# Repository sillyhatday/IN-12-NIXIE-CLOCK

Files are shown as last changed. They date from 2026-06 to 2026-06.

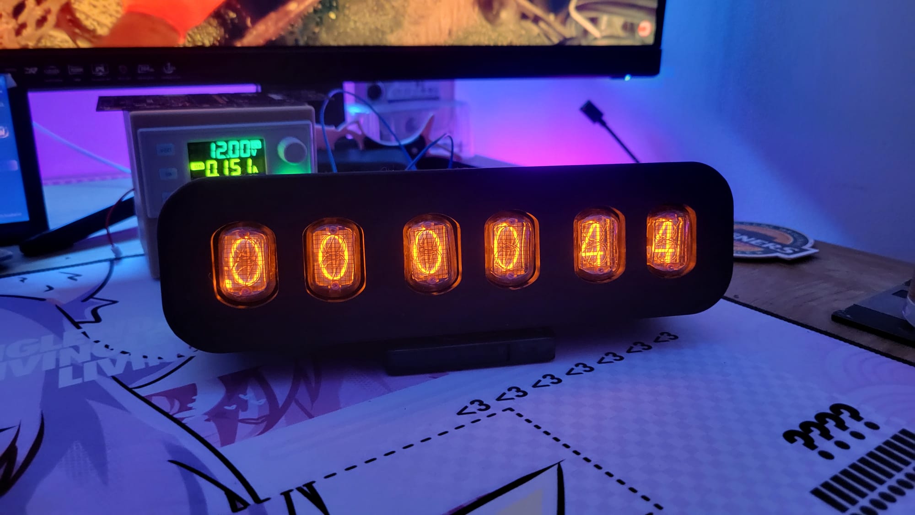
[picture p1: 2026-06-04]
PHOTOS & RENDERS/nixie clock front.jpeg

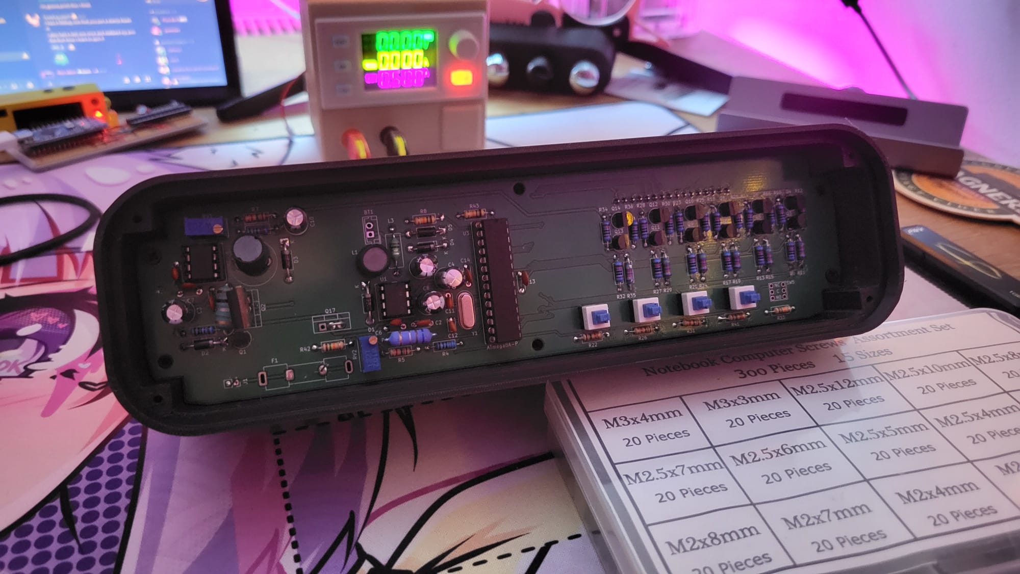
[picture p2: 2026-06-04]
PHOTOS & RENDERS/nixie clock back.jpeg

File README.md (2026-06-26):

# IN-12 Nixie Tube Clock

## Introduction

This clock was designed with the idea of using IN-12 Nixie Tubes as its display. The design was intended to look similar to something from the 1960s with a cyberpunk style. I'm not sure I have managed this or not. I think it is more art deco style.

This did not work out and I went for something that took inspo from the 1950s. I'd say more Fallout than cyberpunk. Maybe American diner or 50's American car. I like it.

The design is to be modular and 3D printing or machining friendly. The final build I would like making from aluminium or stainless steel.

---

## 🔷 Description

The internal electronics are mounted on two PCBs with a connecting pin header. One PCB for power supplies and main logic, the second for the displays and display driver. The choice of putting the display driver on the display PCB was to reduce the amount board to board connections.

The clock housing is keyed to the cut outs in the PCBs. It's not possible to put them in the wron gplace.

The logic board contains two power supplies. One power supply is for the display tube anodes. The second power supply provides power to the logic circuit.

A 9 - 12v DC supply was decided based on testing. The system will operate from 8 to 16v on the input. I have been running mine at 9v as that is supported by more USB C power supplies than 12v.

>[!NOTE]
>Before building, decide if you will use NiMH or Alkaline batteries for backup batteries. If using non-rechargable, do not populate R39 <br>
>I suggest using the ATmega328 over the ATmega8 for lower standby power and longer operation on backup batteries. <br>
>A description of operations can be found [HERE](ClockFunctions.md)

---

## 🫐 Progress

### 🟢 Done
- First revision of PCBs
- Working firmware with some features implemented.
- Stable high voltage power supply
- Case design first revision made
- All remaining case parts, buttons, legs, back cover.
- Updated PCB & fixed errors. Changed fuse, standby circuit, rearranged PCB.
- Added onboard USB-C 9 - 12v support.
- Finished adding firmware features, standby, battery backup, EEPROM clear.
- Porting to ATMEGA328 to use lower voltage and more efficient core, LOD 1.8v vs LOD 2.7v.
- Finishing case cosmetics.
- Digit ghosting fix. Problem in hardware somewhere.
- Standby code needs inverting for new 180v power control circuit.

### 🟡 Working On
- Power measurement testing. MCU power reduction on battery power.
- Tidying up lettering on the back.
- New photos of finished product and new PCBs
- LCSC or Mouser cart ready to buy.

### ⚪ Next
- Create prebuild mouser cart

---

## Photos

>[!TIP]
>Some build images can be seen [here](https://github.com/sillyhatday/IN-12-NIXIE-CLOCK/blob/main/CONCEPT%26BUILD.md)

### Complete
NixieClockFinished
nixie iv6

>[!NOTE]
>IV-6 Clock project on top. To be broken for parts for something better.

### Final PCB

NixieClockPCB

---

## Complete Parts List

| Part | Part No | Qty |
| --- | --- | --- |
| JST Connector | - | 1 |
| Capacitor | 100nF | 5 |
| Capacitor | 20pF | 2 |
| Capacitor | 1nF | 1 |
| Capacitor | 220pF | 1 |
| Capacitor | 4.7uF | 1 |
| Capacitor | 100uF | 4 |
| Diode | 1N5819 | 4 |
| Diode | UF4007 | 1 |
| Fuse | 300mA | 1 |
| Pin Header | 1x2 | 1 |
| Pin Header | 1x16 | 1 |
| Pin Socket | 1x16 | 1 |
| Inductor | 100uH | 1 |
| Inductor | 220uH | 1 |
| Inductor | 1uH | 1 |
| Transistor | BC516 1 |
| Transistor | KSP92 | 6 |
| Transistor | MPSA42 | 6 |
| Transistor | 2N3904 | 1 |
| MOSFET | IRF9540N | 1 |
| MOSFET | IRF740 | 1 |
| Resistor | 0R75 | 1 |
| Resistor | 0R1 | 1 |
| Resistor | 10K | 21 |
| Resistor | 412K | 6 |
| Resistor | 1K | 5 |
| Resistor | 15K | 1 |
| Resistor | 4K7 | 1 |
| Resistor | 100K | 1 |
| Resistor | 6K8 | 1 |
| Resistor | 1K5 | 2 |
| Resistor | 220K | 1 |
| Potentiometer | 2K | 1 |
| Potentiometer | 1K | 1 |
| Button | SHOU HAN 5.8 WSPT | 4 |
| Button | SHOU HAN 5.8 WSPT | 1 |
| MCU | ATMEGA8 | 1 |
| IC | MC34063A | 2 |
| IC | K155ID1 | 1 |
| Tube | IN-12 Nixie | 6 |
| Crystal | 1MHz | 1 |

---

## 💻 Firmware Changelog

| Version | Status | Notes |
| --- | --- | ----- |
| V1.0.0  | Initial | A generally functioning clock. 6 Digits for hours, minutes and seconds. 24 hour mode only. Flashing colon function in time with seconds changing. Reset button to clear contents of hours, minutes and seconds counters. Runs on ATmega8A and Atmega328P at 16MHz external crystal |
| V1.1.0  | Defunct | Fixed bug with hours counter not resetting properly when reset button pressed. Didn't clear hours count. Fixed bug with hours being able to go past 23 when using hours button. Incorrect modulo math |
| V1.2.0  | Defunct | 12 hour time mode added. Selectable with button. Keeps time when switching to 12 hour mode only |
| V1.3.0  | Defunct | 12 hour mode improved. No longer screwing with the hours counter. Leaving that counter alone and translating the 24 hour format on the fly. Now keeps time switching back and forth between 12/24h modes. Added display function to show what hour mode the system has been switched to. Display routine for showing the hour mode written from scratch due to brightness increase when multiplexing 2 digits vs 6 |
| V1.3.1  | Defunct | Fixed a bug caused by adding 12 hour mode functionality where in normal operation, the time doesn't wrap at 24 back to 0 |
| V1.4.0  | Defunct | Added battery backup mode to disable the MCU trying to display digits on the Nixies when 12v input is removed. Hope to save some power for running on battery power |
| V1.4.5  | Defunct | Updated the dev board to bring all features back in the code. Testing required. Moved button logic into one function. Now it is called from main |
| V1.5.0  | Defunct | Added counter for number of hours clock has been running in total. Display mode triggered when button is pressed. Hijacked the reset button for development. Run time is saved into EEPROM at addresses 0, 1, 2, 3 for unsigned long. Routine runs once. With new MCU addresses are cleared at boot and flag set in address 4 to indicate the EEPROM addresses are initialised. On boot the flag is checked, so as not to overwrite the runtime count |
V1.5.1-1.5.4 | Defunct | Various different attempts at solving the syncing issue of the colon with the seconds tick. The bug appeared after more testing. Removed ISR function that was tried in attempt to keep things in sync and in phase. Rewrote entire colon handling from scratch. Modified timer function to count 500mS ticks to use as reference for colon. Two ticks now count 1 second. Used GPIO pin to control blanking of CD4511 outputs. Removed long complex routine for multiplexing 2 digits. Reduced down to an if statement in main multiplex |
| V1.6.0  | Defunct | Added back in second multiplex routine but inside the main multiplex behind an if statement. Can't recall why I had to add it back in. Must have been buggy. At least it's more stream lined than before. Improved speed of multiplex function by tracking which digit was last displayed and only blanking that one, not all six. Huge improvement to the display crispness. Blanking just one digit saves 83% of the time it took to blank 6 digits. 5 of those did not need to be. Used digitalWriteFast library as a stop gap to using direct port manipulation much later on |
| V1.6.1  | Defunct | General tidy up of formatting. Added lots of comments and removed most comments from each line unless needed for clarity. Most comments are in the top of each function in one text block. Removed some unused variables. Removed reset button references ready to trigger reset on mode button hold, or status hold |
| V1.6.5  | Defunct | Once again removed the second multiplex function for two digit mode. No longer using any digitalWriteFast in multiplex function. Blanking digits with invalid data sent to the CD4511. This was tried before and didn't work as I didn't remember to expand the array for the new data to send. It was sending random data in RAM at that moment instead! This was needed realising that the nixie tube driver doe not have a blanking input. Nixie PSU gate control output added ready for prototype PSU and logic PCB |
| V1.7.0 | Defunct | Removed some debugging code using GPIO pins. Added an output to drive a MOSFET gate that will control the 180v boost supply, depending on 12v input being present or not. Code was added onto the section controlling display blanking as the input to perform the display blanking was already implemented |
| V1.7.1 | Defunct | Changed setup function to deal with stored EEPROM data differently and how it is initialised on first power up. Added in a basic check routine to confirm EEPROM is working, else show 999,999 on the run time display. Not sure it was needed as the problems I was having went away when shifting the EEPROM storage addresses. I think this unknown Aliexpress chip is somewhat dodgy. It is probably worn out. The chip has been reprinted on top while the underside is beat to hell |
| V1.8.0 | Defunct | Implemented a multi-function button routine. Status button now serves dual function. It is a new function in code that handles just that button, where it should be merged with the existing button handler. I don't plan on any more multi function buttons, so I'll leave this alone. Holding the status button now does a software reset of the time. Pressing the button works as before but activates on release of the button, not on the press |
| V1.8.1 | Defunct | Fixed a bug that caused the run time counter to roll over at 255 |
| V2.0.0 | Defunct | Complete rewrite of the whole software. Code is built around state machines now, no more blocking flag everywhere. Some features have been removed or not yet implemented. Missing code for standby function. Removed blinking colon, don't like it anymore |
| V2.1.0 | Defunct | Code modified to work on the real nixie tube setup. Only small things like the multiplex scan direction and stuff I've forgotten. Fixed bug with button debouncing not working great since the re-write. Attempted to fix problem with run time hours data getting messed up. Not wure why as it didnt have any issue on the dev board |
| V2.2.0 | Defunct | Added standby feature back to system. Power loss or power switch perform the same function. Displays off, 180v supply off, sleep cpu. CPU wakes once per second to keep time and check if escape standby. Not sure eeprom fix is working still. Need to add code to stop eeprom code being updated while in sleep. It's only to track tube run time |
| V2.2.3 | Current | Moved software over to ATmega328. Implemented clock divider to reduce clock speed to 2MHz. At 1MHz there was a slight percievable flicker when seconds incremented |

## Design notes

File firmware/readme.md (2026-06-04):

Firmware archive

V2.0 is a near full rewrite of the software after I learned more about programming. It's still not perfect and missing features.

V2.1 is the only version that works on the nixie tube clock build, all previous versions only work on the development board.

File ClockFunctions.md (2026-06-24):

## 🟦 Clock Functions

* The clock will power on and display time starting at 00:00:00 when it is plugged in. Whenever the clock is powered on, it will default to 24 hour mode. This only applies to the first time it is powered or the backup battery is depleted.

* The "hours" button is to increment the hours digits to the desired time, the same logic applies to the "minutes" button. The seconds count cannot be set. If the user wishes to sync the clock down to the second, the reset function can be used to set the clock back to 00:00:00. NEEDS REIMPLEMENTING IN V2.0

* To reset the clock to 00:00:00, hold down the "status" button for 3 seconds. Continuing to hold the button will keep the clock at this time until it is released, allowing it to be synchronised easily. NOT IMPLEMENTED

* The "status" button is multi-function. It is used to reset the clock time and to display the total run time of the clock with the display tubes powered on. A single press of the "status" button will show the hours counter. This information is stored in EEPROM memory and is saved permanently, unless the micro controller is reprogrammed and EEPROM is selected for erase. Powering off the clock, by removing the DC supply, and/or removing the internal backup battery, will not erase the counter.

* The counter uses an internal timer to record data. Pressing the "hours" button does not increase the recorded hours.

* When the clock is removed from USB-C power, the displays will turn off. Internally the clock is still running and keeping time, providing the backup battery is not depleted. This same condition can be entered using the "standby" button. This simulates the removal of USB-C power, but will not deplete the backup battery. The clock will continue to run in this state indefinitely.

* The clock will only record run time, when it is powered by the USB-C input. If the clock is on backup battery, the counter will no longer increment. The same applies for manually putting the clock in standby with the "standby" button.

* A 12 hour mode is selectable with the "mode" button. When the button is pressed, the display will briefly display 12 or 24, depending on the mode that has been set. The button will toggle between 12 and 24 hour modes.

* While the clock is plugged in, the backup batteries are charged at 8 - 11mA depending on the battery state of charge. When the batteries are full, they are charged constantly at 8mA. Due to the battery technology of NiMh, they can be left charging at a low current for a long time. If this function is not wanted, omit R39 and the batteries will not be charged. As the function of the batteries is to keep time during a power outage, having them charge is not critical. While plugged into USB-C power, even when in standby, they are being charged. It's likely the life of the batteries will be shortened from being on charge for so long, it may be better to remove the batteries and recharge them manually every 6 months or replace alkaline batteries once a year.

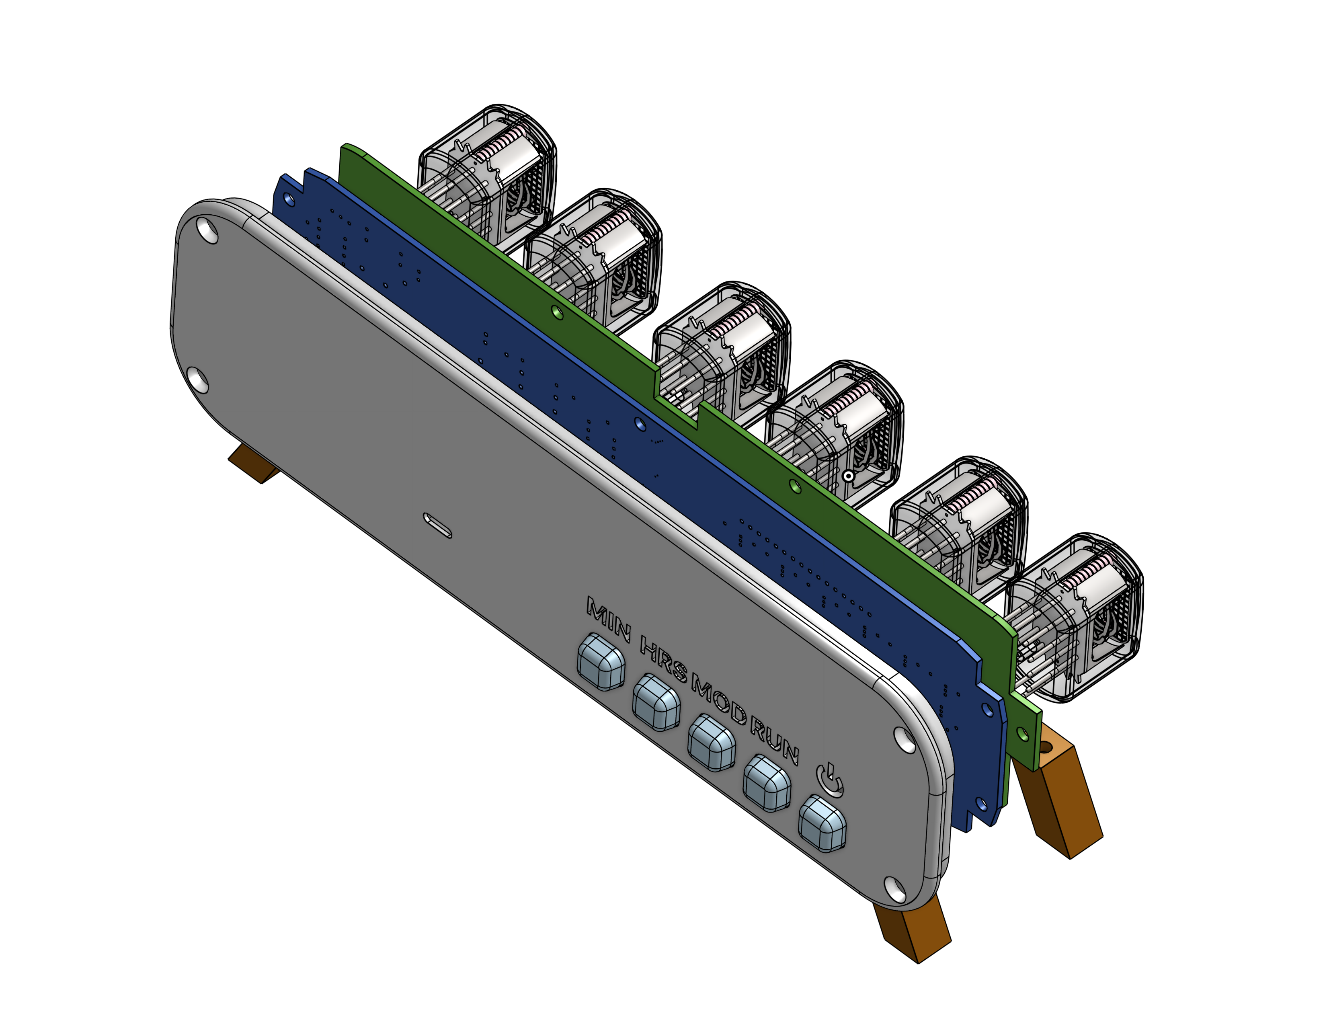
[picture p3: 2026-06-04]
PHOTOS & RENDERS/Nixie clock angled back view no body.png

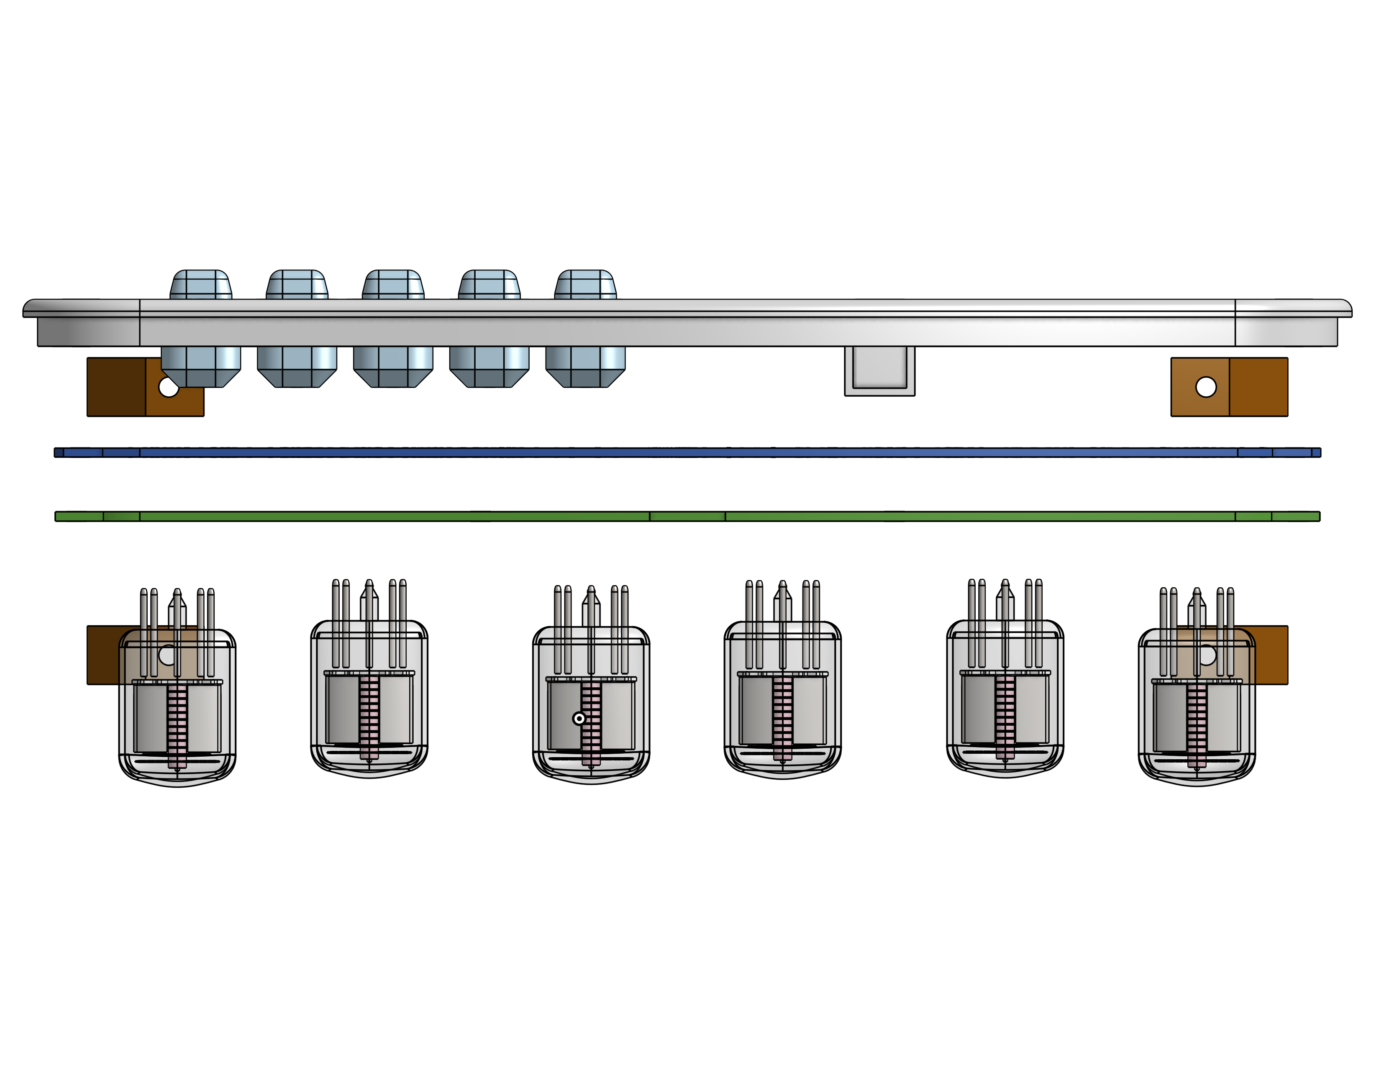
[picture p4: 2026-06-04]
PHOTOS & RENDERS/Nixie Clock Top View No Body.png

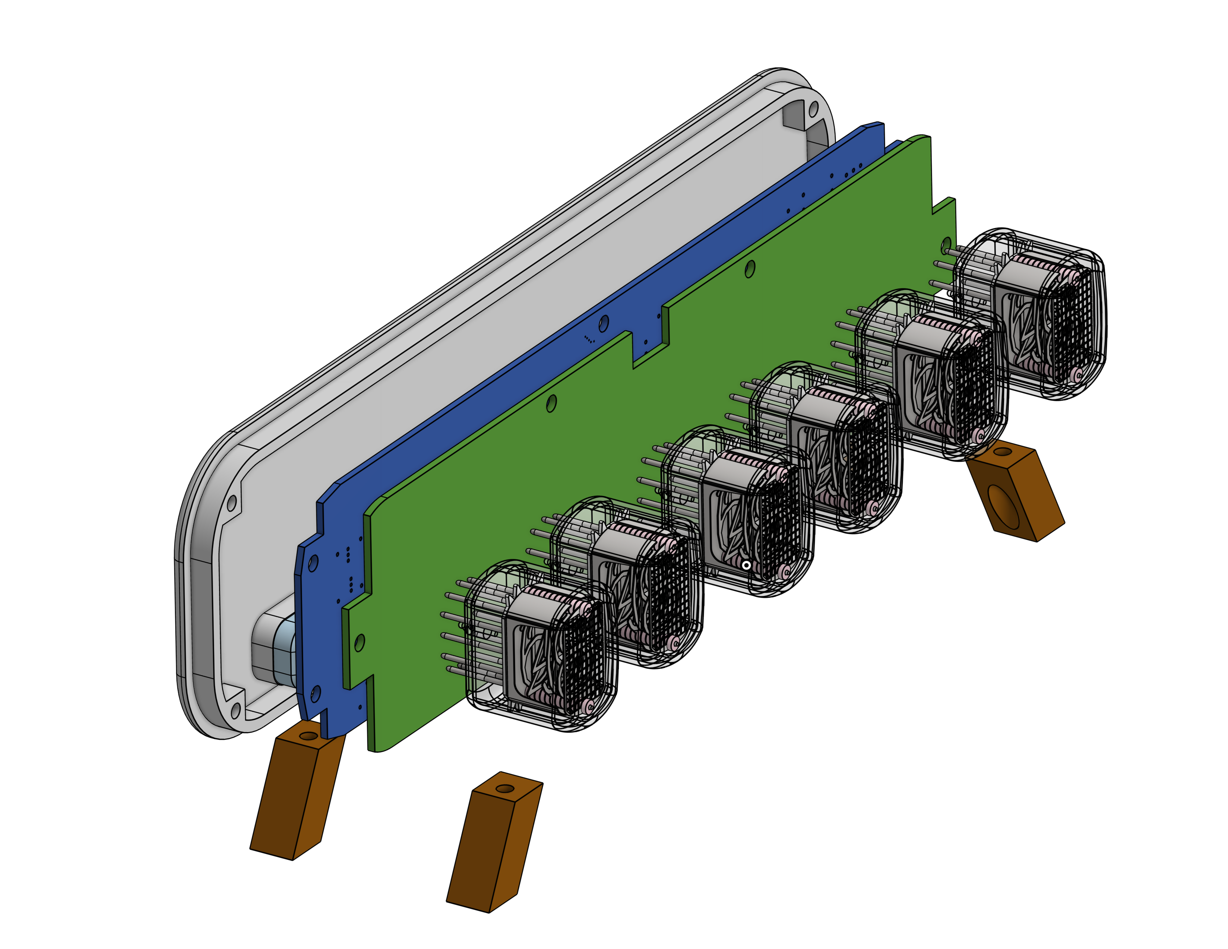
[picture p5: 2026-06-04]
PHOTOS & RENDERS/Nixie clock angled front view no body.png

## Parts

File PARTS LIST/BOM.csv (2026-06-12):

Logic PCB:
Designator | Footprint | Quantity | Value | LCSC Part # | LCSC Link | Notes
BT1, J1 | JST_EH_B2B-EH-A_1x02_P2.50mm_Vertical | 1 | Battery | C158012 | https://www.lcsc.com/product-detail/C158012.html
C1, C13, C14, C2, C7 | C_Disc_D3.4mm_W2.1mm_P2.50mm | 5 | 100nF | C2832506 | https://www.lcsc.com/product-detail/C2832506.html
C10 | CP_Radial_D6.3mm_P2.50mm | 1 | 4.7uF | C106368 | https://www.lcsc.com/product-detail/C106368.html
C11, C12 | C_Disc_D3.4mm_W2.1mm_P2.50mm | 2 | 20pF | C19712497 | https://www.lcsc.com/product-detail/C19712497.html
C3, C4, C8, C9 | CP_Radial_D6.3mm_P2.50mm | 4 | 100uF | C112509 | https://www.lcsc.com/product-detail/C112509.html
C5 | C_Disc_D3.4mm_W2.1mm_P2.50mm | 1 | 1nF | C2832504 | https://www.lcsc.com/product-detail/C2832504.html
C6 | C_Disc_D3.4mm_W2.1mm_P2.50mm | 1 | 220pF | C2169557 | https://www.lcsc.com/product-detail/C2169557.html
D1, D2, D4 | D_DO-41_SOD81_P10.16mm_Horizontal | 3 | 1N5819 | C110032 | https://www.lcsc.com/product-detail/C110032.html
D3 | D_DO-41_SOD81_P10.16mm_Horizontal | 1 | UF4007 | C511041 | https://www.lcsc.com/product-detail/C511041.html
D5 | D_DO-41_SOD81_P10.16mm_Horizontal | 1 | SB160 | C2978860 | https://www.lcsc.com/product-detail/C2978860.html
F1 | Fuseholder_Cylinder-5x20mm_Stelvio-Kontek_PTF78_Horizontal_Open | 1 | Fuse | C206887 | https://www.lcsc.com/product-detail/C206887.html
J3 | PinSocket_1x16_P2.54mm_Vertical | 1 | Logic Out | C7501270 | https://www.lcsc.com/product-detail/C7501270.html
L1 | L_Radial_D8.7mm_P5.00mm_Fastron_07HCP | 1 | 100uH | C2924234 | https://www.lcsc.com/product-detail/C2924234.html
L2 | L_Radial_D8.7mm_P5.00mm_Fastron_07HCP | 1 | 150uH | C72625 | https://www.lcsc.com/product-detail/C72625.html
L3 | L_Axial_L6.6mm_D2.7mm_P10.16mm_Horizontal_Vishay_IM-2 | 1 | 1uH | C19704338 | https://www.lcsc.com/product-detail/C19704338.html
Q1 | TO-92_Inline | 1 | BC516 | C14617 | https://www.lcsc.com/product-detail/C14617.html
Q10, Q12, Q14, Q4, Q6, Q8 | TO-92_Inline | 6 | KSP92BU | C231893 | https://www.lcsc.com/product-detail/C231893.html
Q11, Q13, Q3, Q5, Q7, Q9 | TO-92_Inline | 6 | MPSA42 | C719821 | https://www.lcsc.com/product-detail/C719821.html
Q15 | TO-220-3_Vertical | 1 | IRF9540N | C2575 | https://www.lcsc.com/product-detail/C2575.html
Q16 | TO-92_Inline | 1 | 2N3904 | C124482 | https://www.lcsc.com/product-detail/C124482.html
Q2 | TO-220-3_Vertical | 1 | IRF740 | C2570 | https://www.lcsc.com/product-detail/C2570.html
R1 | R_Axial_DIN0414_L11.9mm_D4.5mm_P15.24mm_Horizontal | 1 | 0R75 | C75144 | https://www.lcsc.com/product-detail/C75144.html
R10, R12, R13, R14, R16, R17, R18, R20, R21, R23, R25, R27, R28, R30, R32, R34, R36, R38, R42, R43, R8, R9 | R_Axial_DIN0207_L6.3mm_D2.5mm_P10.16mm_Horizontal | 22 | 10K | C2903232 | https://www.lcsc.com/product-detail/C2903232.html
R11, R15, R19, R24, R29, R35 | R_Axial_DIN0207_L6.3mm_D2.5mm_P10.16mm_Horizontal | 6 | 422K | C1367617 | https://www.lcsc.com/product-detail/C1367617.html
R2 | R_Axial_DIN0414_L11.9mm_D4.5mm_P15.24mm_Horizontal | 1 | 0R1 | C1740730 | https://www.lcsc.com/product-detail/C1740730.html
R22, R26, R3, R31, R41 | R_Axial_DIN0207_L6.3mm_D2.5mm_P10.16mm_Horizontal | 5 | 1K | C1364389 | https://www.lcsc.com/product-detail/C1364389.html
R33 | R_Axial_DIN0207_L6.3mm_D2.5mm_P10.16mm_Horizontal | 1 | 15K | C119351 | https://www.lcsc.com/product-detail/C119351.html
R37 | R_Axial_DIN0207_L6.3mm_D2.5mm_P10.16mm_Horizontal | 1 | 330R | C58577 | https://www.lcsc.com/product-detail/C58577.html
R39 | R_Axial_DIN0207_L6.3mm_D2.5mm_P10.16mm_Horizontal | 1 | 270R | C3463492 | https://www.lcsc.com/product-detail/C3463492.html | Optional
R4 | R_Axial_DIN0207_L6.3mm_D2.5mm_P10.16mm_Horizontal | 1 | 6K8 | C58600 | https://www.lcsc.com/product-detail/C58600.html
R5, R7 | R_Axial_DIN0207_L6.3mm_D2.5mm_P10.16mm_Horizontal | 2 | 1K5 | C173144 | https://www.lcsc.com/product-detail/C173144.html
R6 | R_Axial_DIN0207_L6.3mm_D2.5mm_P10.16mm_Horizontal | 1 | 220K | C172988 | https://www.lcsc.com/product-detail/C172988.html
RV1 | Potentiometer_Bourns_3296W_Vertical | 1 | 2K | C48641845 | https://www.lcsc.com/product-detail/C48641845.html
RV2 | Potentiometer_Bourns_3296W_Vertical | 1 | 1K | C48641912 | https://www.lcsc.com/product-detail/C48641912.html
SW1, SW2, SW3, SW4 | SHOU HAN 5.8 WSPT | 1 | MIN+ | C22363820 | https://www.lcsc.com/product-detail/C22363820.html
SW5 | SHOU HAN 5.8 WSPT | 1 | DISPLAY | C22363819 | https://www.lcsc.com/product-detail/C22363819.html
U1, U2 | DIP-8_W7.62mm_Socket | 2 | MC34063AP | C5180 | https://www.lcsc.com/product-detail/C5180.html
U1, U2 | DIP-8_W7.62mm_Socket | 2 | DIP 8 Socket | C2874007 | https://www.lcsc.com/product-detail/C2874007.html | Optional
U3 | DIP-28_W7.62mm_Socket | 1 | ATmega8A-P | C33901 | https://www.lcsc.com/product-detail/C33901.html
U3 | DIP-28_W7.62mm_Socket | 1 | DIP 28 Socket | C2874014 | https://www.lcsc.com/product-detail/C2874014.html | Optional
Y1 | Crystal_HC49-U_Vertical | 1 | Crystal | C5310734 | https://www.lcsc.com/product-detail/C5310734.html
Display PCB:
Designator | Footprint | Quantity | Value | LCSC Part # | LCSC Link | Notes
J1 | PinHeader_1x16_P2.54mm_Vertical | 1 | Logic In | C7499334 | https://www.lcsc.com/product-detail/C7499334.html
U1, U2, U3, U4, U5, U6 | IN-12 | 6 | IN-12A | N/A | N/A
U7 | DIP-16_W7.62mm_Socket | 1 | KN155 | N/A | N/A
U7 | DIP-16_W7.62mm_Socket | 1 | DIP 16 Socket | C72130 | https://www.lcsc.com/product-detail/C72130.html

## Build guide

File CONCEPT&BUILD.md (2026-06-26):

# Concept & Build

## Rendered Concept
Nixie clock assembled smol
Nixie clock angled rear assembled smol
Nixie clock assembled rear smol

## Internal View
nixie clock internal top view
nixie clock internal front angle
nixie clock internal back angle

## Build
nixiebuild1
nixiebuild2
nixiebuild3
nixiebuild4

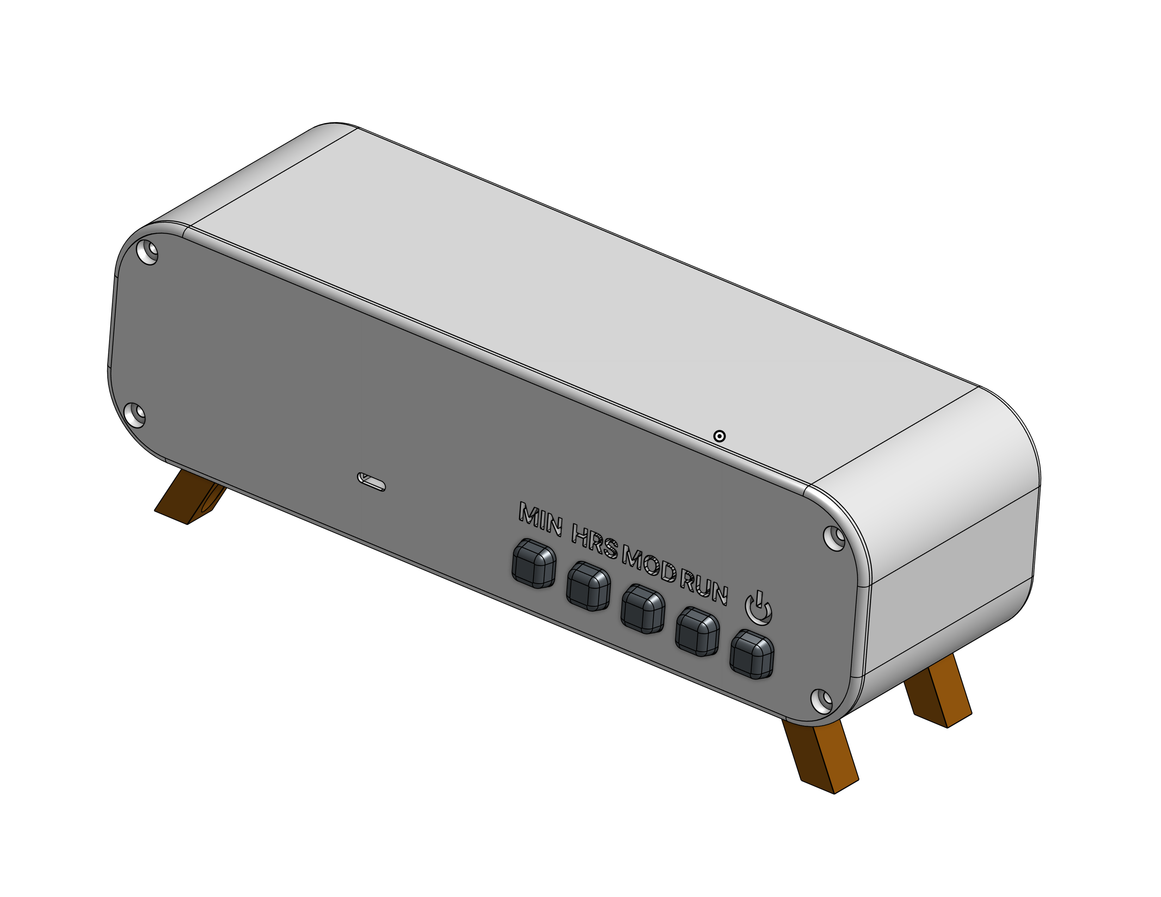
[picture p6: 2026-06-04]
PHOTOS & RENDERS/Nixie clock angled rear assembled.png

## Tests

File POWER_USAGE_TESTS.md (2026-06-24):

# Standby Power Use

>[!IMPORTANT]
>This is a work in progress

>[!NOTE]
>Standby refers to my codes standby mode, running only code needed to track time. <br>
>Sleep idle refers to the AVR hardware sleep.
>LOD watchdog uses power when enabled. This will protect the EEPROM data.

## Standby Testing

### 16MHz Clock

ATMEGA8A @16MHz:

| Standby | Sleep Idle | Analogue Comp Disabled | ADC Disabled | SPI, Timer0 & ADC Clock Disabled | LOD 1.8v Enable | Current @ 2.5v | Power Reduction |
| --- | --- | --- | --- | --- | --- | --- | --- |
| YES | NO | NO | NO | NO | N/A | ------- | --------------- |
| YES | YES | NO | NO | NO | N/A | 6.774mA | --------------- |
| YES | YES | YES | NO | NO | N/A | ------- | --------------- |
| YES | YES | YES | YES | NO | N/A | ------- | --------------- |
| YES | YES | YES | YES | YES | N/A | ------- | --------------- |
| YES | YES | YES | YES | YES | N/A | ------- | --------------- |
| YES | YES | YES | YES | NO | N/A | ------- | --------------- |

ATMEGA328P @16MHz:

| Standby | Sleep Idle | Analogue Comp Disabled | ADC Disabled | SPI, Timer0 & ADC Clock Disabled | LOD 1.8v Enable | Current @ 2.5v | Power Reduction |
| --- | --- | --- | --- | --- | --- | --- | --- |
| YES | NO | NO | NO | NO | NO | 7.288mA | 0% |
| YES | YES | NO | NO | NO | NO | 5.678mA | 28.35% |
| YES | YES | YES | NO | NO | NO | 5.639mA | 29.24% |
| YES | YES | YES | YES | NO | NO | 4.949mA | 47.26% |
| YES | YES | YES | YES | YES | NO | 5.126mA | 42.17% |
| YES | YES | YES | YES | YES | YES | ------- | ------- |
| YES | YES | YES | YES | NO | YES | 5.539mA | 31.57% |

## 4MHz Clock

ATMEGA8A @4MHz:

| Standby | Sleep Idle | Analogue Comp Disabled | ADC Disabled | SPI, Timer0 & ADC Clock Disabled | LOD 1.8v Enable | Current @ 2.5v | Power Reduction |
| --- | --- | --- | --- | --- | --- | --- | --- |
| YES | NO | NO | NO | NO | N/A | ------- | --------------- |
| YES | YES | NO | NO | NO | N/A | ------- | --------------- |
| YES | YES | YES | NO | NO | N/A | ------- | --------------- |
| YES | YES | YES | YES | NO | N/A | ------- | --------------- |
| YES | YES | YES | YES | YES | N/A | ------- | --------------- |
| YES | YES | YES | YES | YES | N/A | ------- | --------------- |
| YES | YES | YES | YES | NO | N/A | ------- | --------------- |

ATMEGA328P @4MHz:

| Standby | Sleep Idle | Analogue Comp Disabled | ADC Disabled | SPI, Timer0 & ADC Clock Disabled | LOD 1.8v Enable | Current @ 2.5v | Power Reduction |
| --- | --- | --- | --- | --- | --- | --- | --- |
| YES | NO | NO | NO | NO | NO | ------- | --------------- |
| YES | YES | NO | NO | NO | NO | ------- | --------------- |
| YES | YES | YES | NO | NO | NO | ------- | --------------- |
| YES | YES | YES | YES | NO | NO | ------- | --------------- |
| YES | YES | YES | YES | YES | NO | ------- | --------------- |
| YES | YES | YES | YES | YES | YES | ------- | --------------- |
| YES | YES | YES | YES | NO | YES | ------- | --------------- |

## 2MHz Clock

ATMEGA8A @2MHz:

| Standby | Sleep Idle | Analogue Comp Disabled | ADC Disabled | SPI, Timer0 & ADC Clock Disabled | LOD 1.8v Enable | Current @ 2.5v | Power Reduction |
| --- | --- | --- | --- | --- | --- | --- | --- |
| YES | NO | NO | NO | NO | N/A | ------- | --------------- |
| YES | YES | NO | NO | NO | N/A | ------- | --------------- |
| YES | YES | YES | NO | NO | N/A | ------- | --------------- |
| YES | YES | YES | YES | NO | N/A | ------- | --------------- |
| YES | YES | YES | YES | YES | N/A | ------- | --------------- |
| YES | YES | YES | YES | YES | N/A | ------- | --------------- |
| YES | YES | YES | YES | NO | N/A | ------- | --------------- |

ATMEGA328P @2MHz (Using CLKPR /8):

| Standby | Sleep Idle | Analogue Comp Disabled | ADC Disabled | SPI, Timer0 & ADC Clock Disabled | LOD 1.8v Enable | Current @ 2.5v | Power Reduction |
| --- | --- | --- | --- | --- | --- | --- | --- |
| YES | NO | NO | NO | NO | NO | ------- | --------------- |
| YES | YES | NO | NO | NO | NO | ------- | --------------- |
| YES | YES | YES | NO | NO | NO | ------- | --------------- |
| YES | YES | YES | YES | NO | NO | ------- | --------------- |
| YES | YES | YES | YES | YES | NO | ------- | --------------- |
| YES | YES | YES | YES | YES | YES | 4.071mA | --------------- |
| YES | YES | YES | YES | NO | YES | 4.057mA | --------------- |

## Normal Operation

### ATMEGA8A:

| Clock Speed | Input Current | Input Voltage | Input Power |
| --- | --- | --- | --- |
| @16MHz | - | - | - |
| @4MHz | - | - | - |
| @1MHz | - | - | - |

### ATMEGA328P:

| Clock Speed | Input Current | Input Voltage | Input Power |
| --- | --- | --- | --- |
| @16MHz | - | - | - |
| @4MHz | - | - | - |
| @1MHz | - | - | - |

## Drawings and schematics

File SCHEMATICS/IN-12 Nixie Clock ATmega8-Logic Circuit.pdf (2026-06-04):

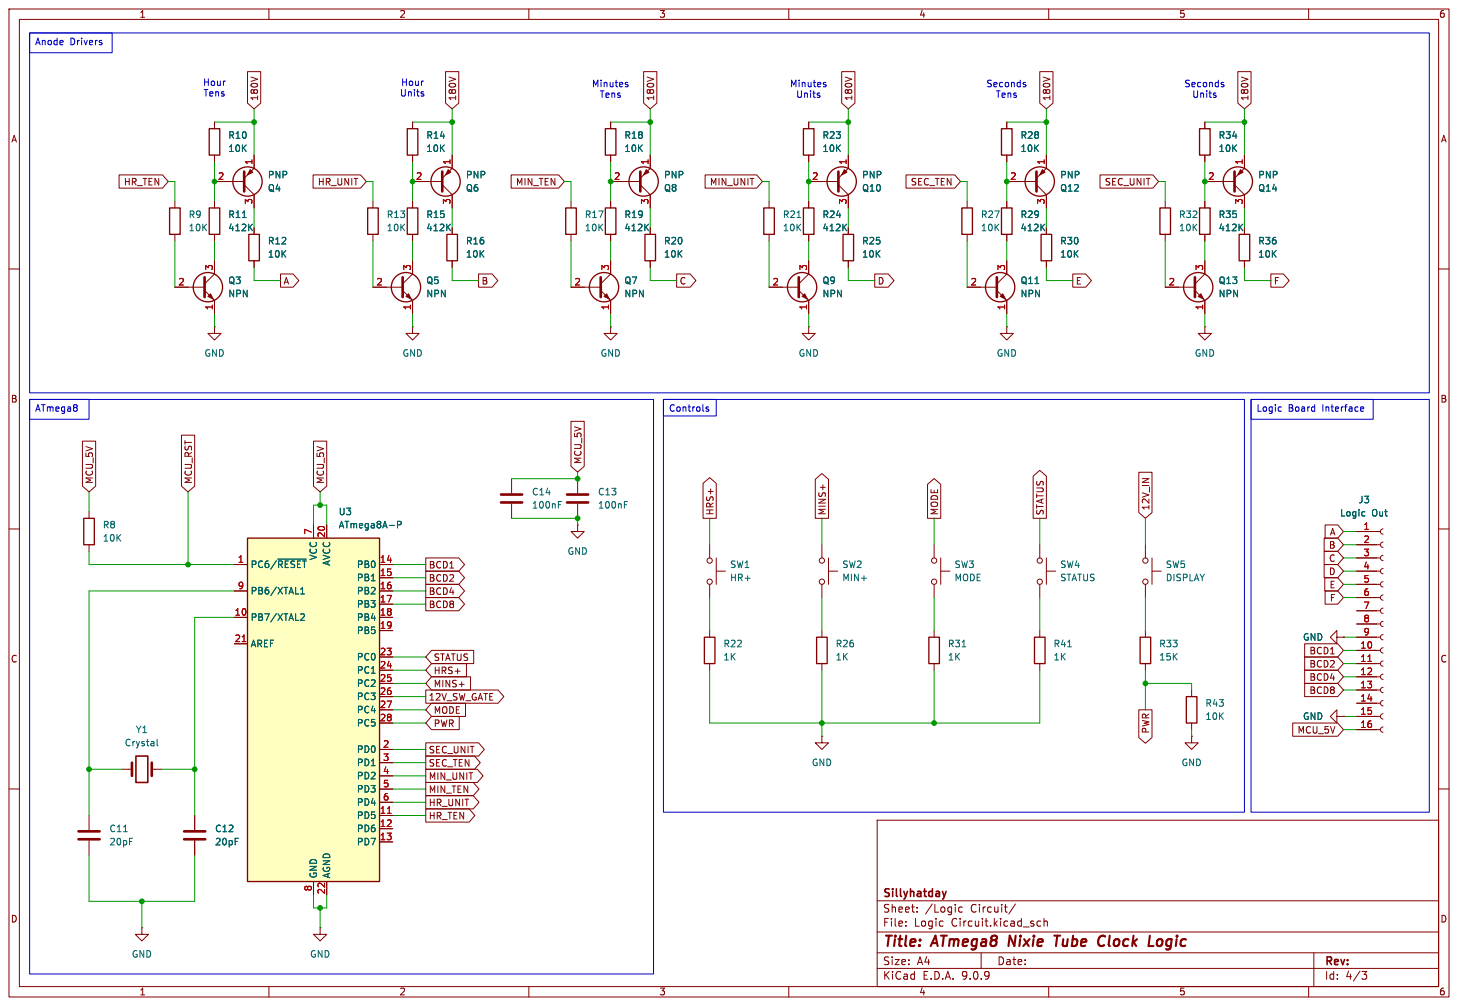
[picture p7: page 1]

3 1 Q12 PNP 180V MODE PWR STATUS

Id: 4/3 Title: ATmega8 Nixie Tube Clock Logic

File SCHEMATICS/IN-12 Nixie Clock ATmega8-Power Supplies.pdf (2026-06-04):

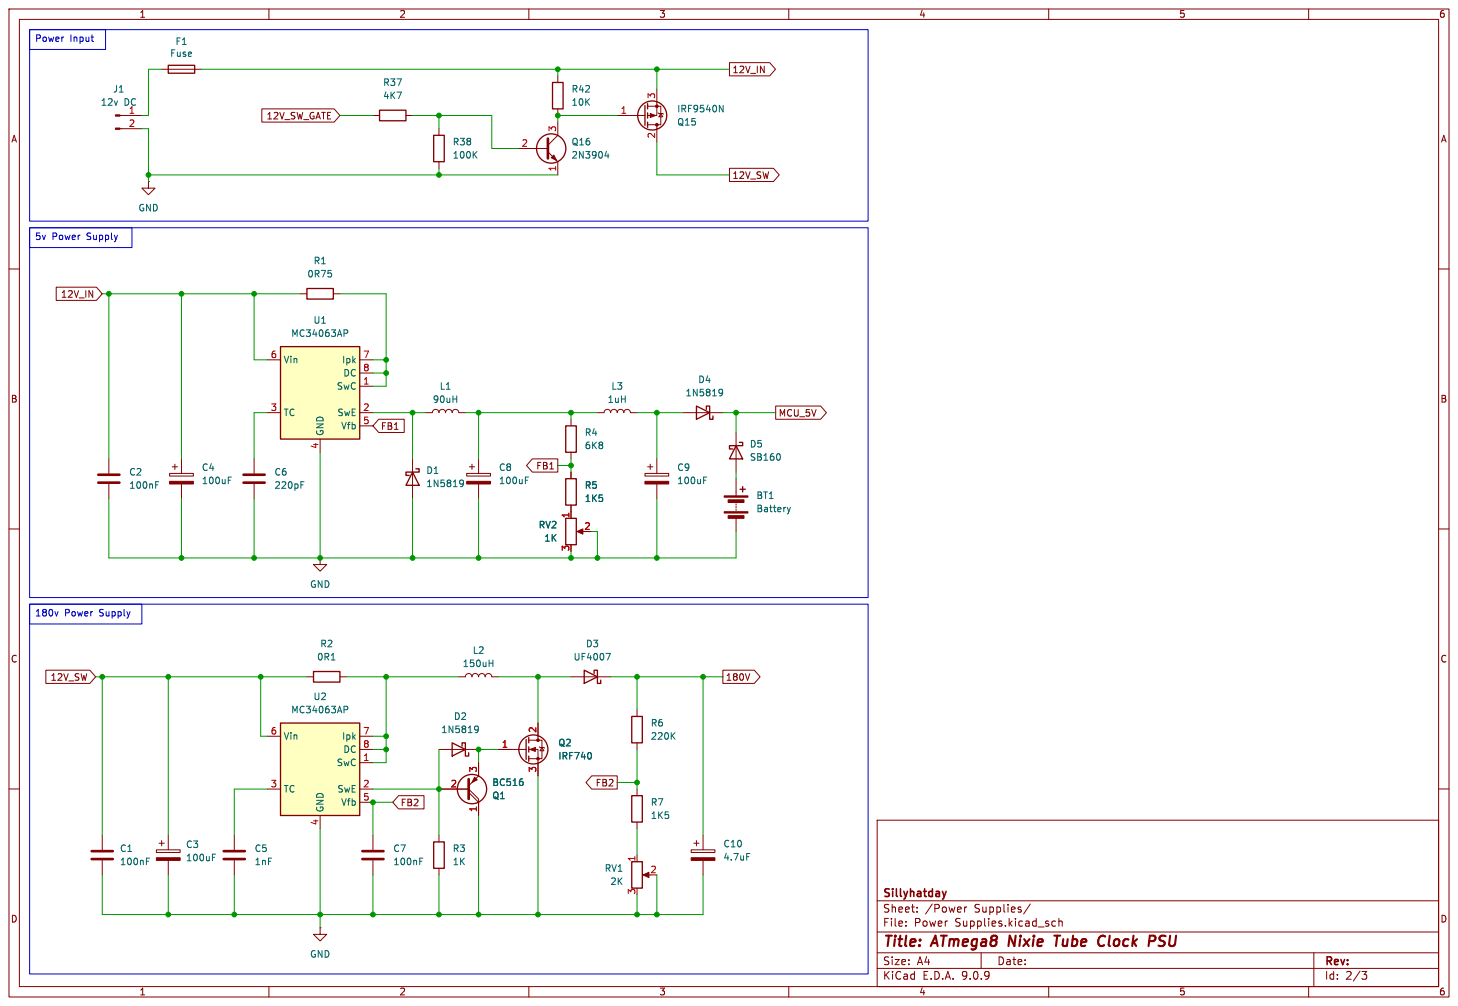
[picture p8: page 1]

Id: 2/3 Title: ATmega8 Nixie Tube Clock PSU

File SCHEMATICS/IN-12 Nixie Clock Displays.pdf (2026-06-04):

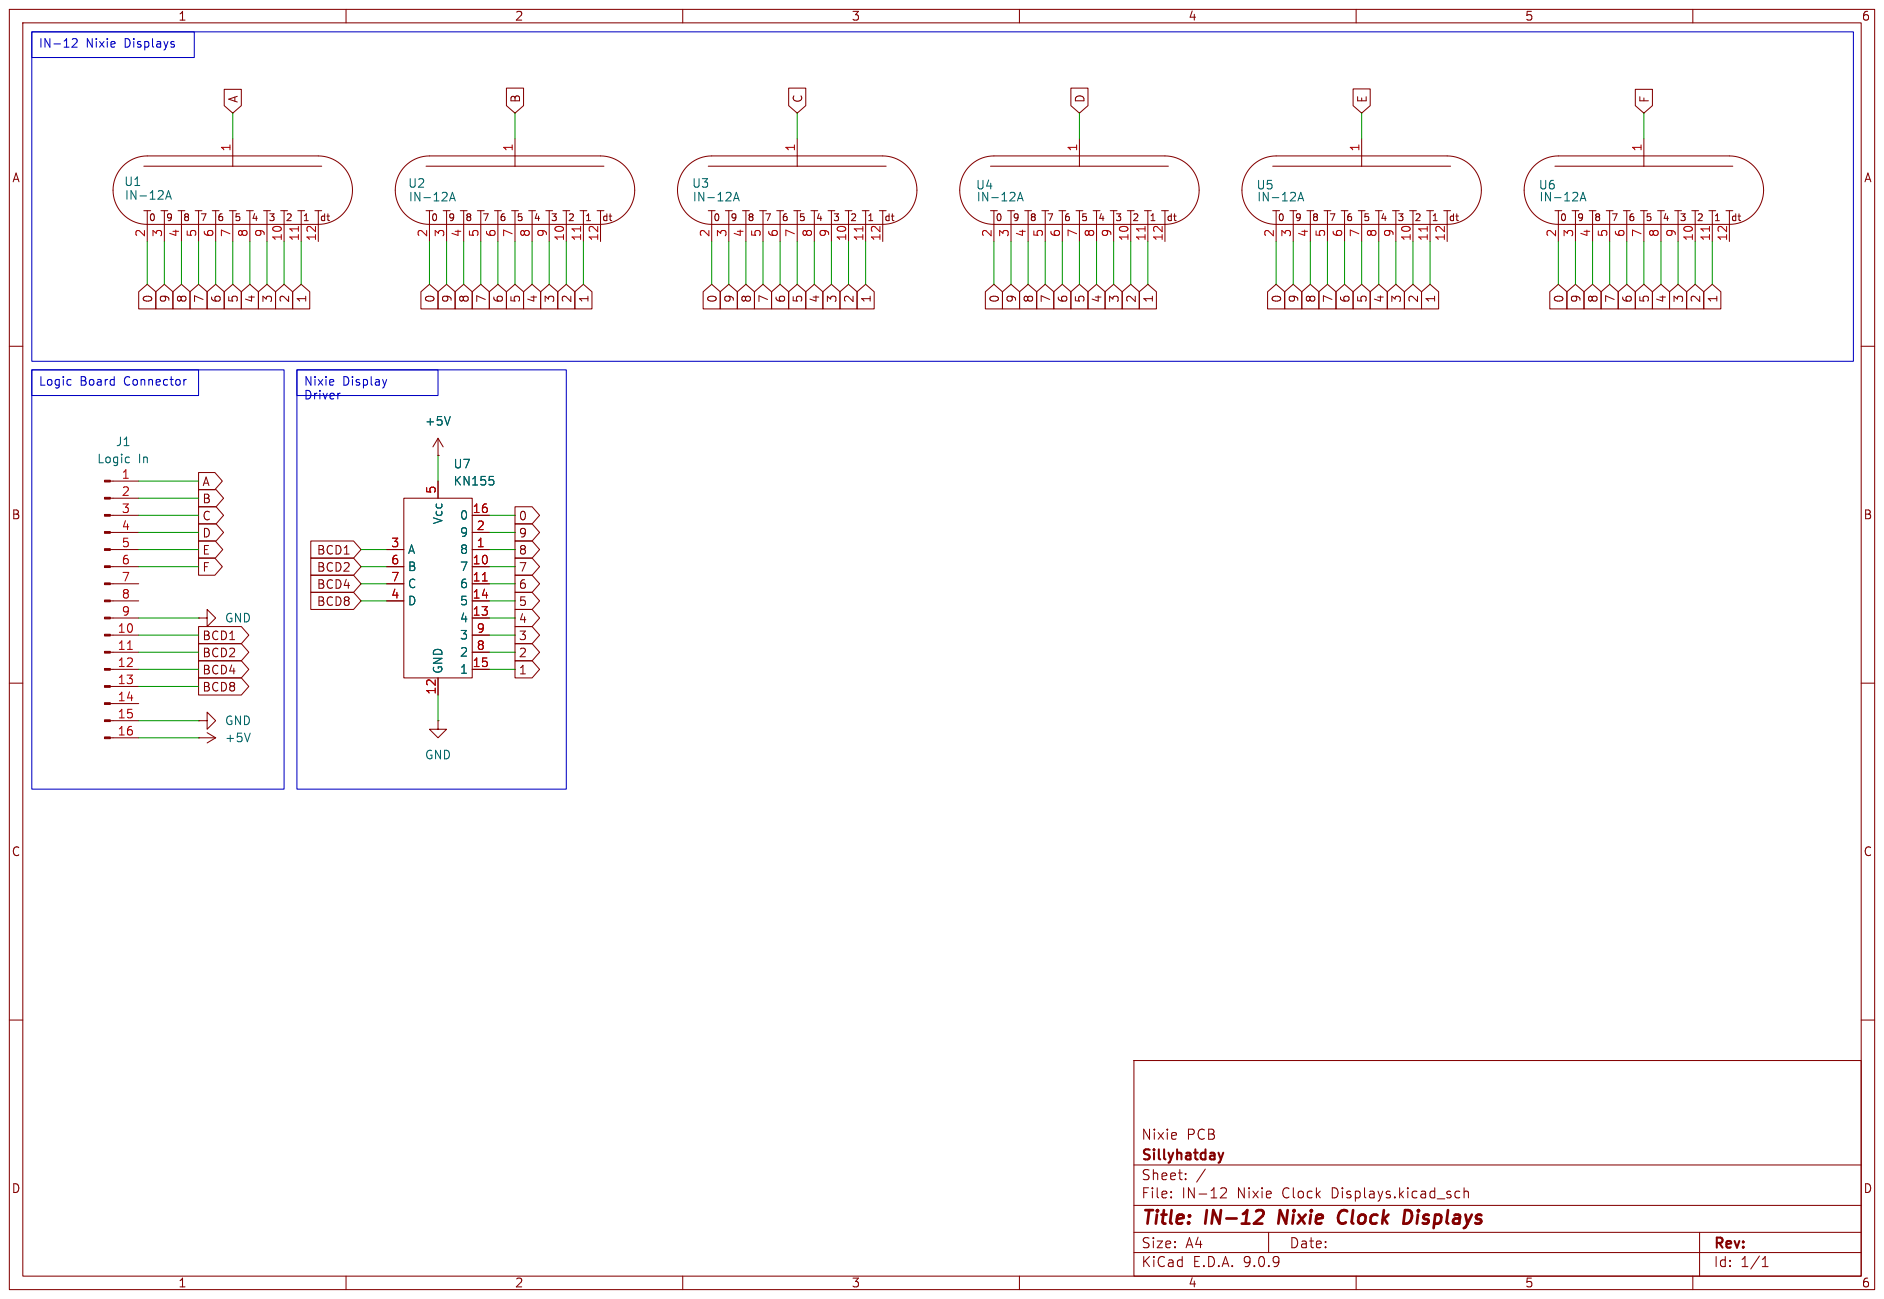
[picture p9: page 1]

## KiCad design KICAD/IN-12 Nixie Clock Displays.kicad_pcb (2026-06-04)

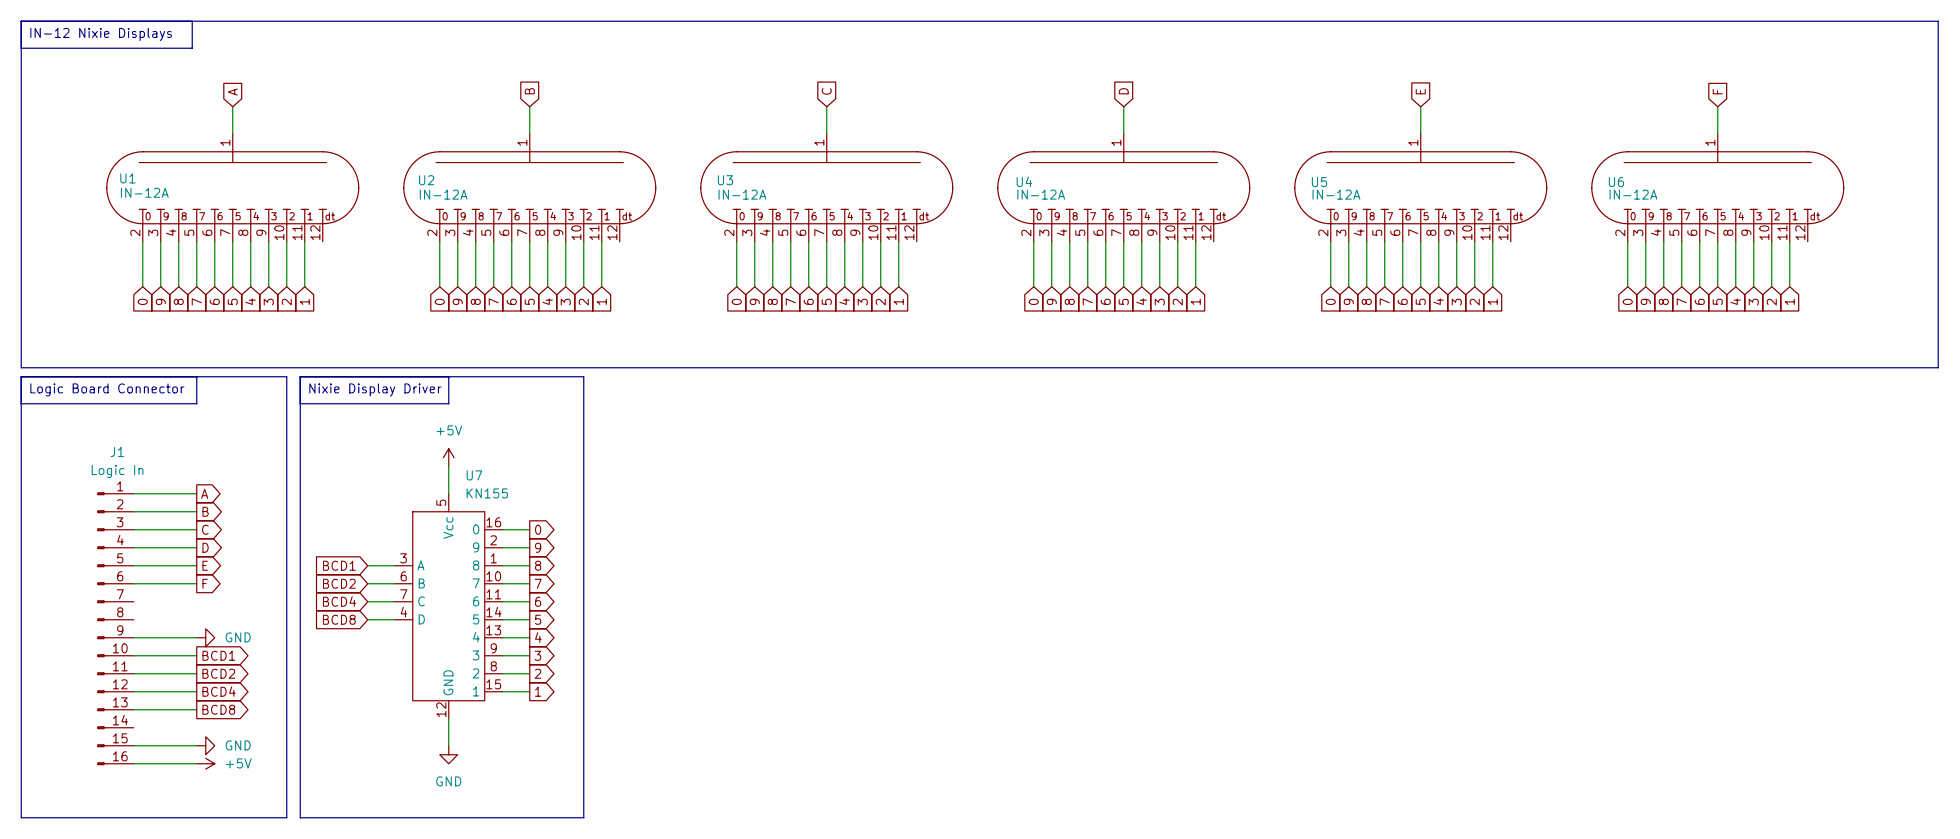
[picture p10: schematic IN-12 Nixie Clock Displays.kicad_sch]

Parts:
J1: Logic In; PinHeader_1x16_P2.54mm_Vertical
U1, U2, U3, U4, U5, U6: IN-12A; IN-12
U7: KN155; DIP-16_W7.62mm_Socket

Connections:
0: U1.2, U2.2, U3.2, U4.2, U5.2, U6.2, U7.16 (0)
1: U1.11, U2.11, U3.11, U4.11, U5.11, U6.11, U7.15 (1)
2: U1.10, U2.10, U3.10, U4.10, U5.10, U6.10, U7.8 (2)
3: U1.9, U2.9, U3.9, U4.9, U5.9, U6.9, U7.9 (3)
4: U1.8, U2.8, U3.8, U4.8, U5.8, U6.8, U7.13 (4)
5: U1.7, U2.7, U3.7, U4.7, U5.7, U6.7, U7.14 (5)
6: U1.6, U2.6, U3.6, U4.6, U5.6, U6.6, U7.11 (6)
7: U1.5, U2.5, U3.5, U4.5, U5.5, U6.5, U7.10 (7)
8: U1.4, U2.4, U3.4, U4.4, U5.4, U6.4, U7.1 (8)
9: U1.3, U2.3, U3.3, U4.3, U5.3, U6.3, U7.2 (9)
+5V: J1.16, U7.5 (Vcc)
A: J1.1, U1.1
B: J1.2, U2.1
BCD1: J1.10, U7.3 (A)
BCD2: J1.11, U7.6 (B)
BCD4: J1.12, U7.7 (C)
BCD8: J1.13, U7.4 (D)
C: J1.3, U3.1
D: J1.4, U4.1
E: J1.5, U5.1
F: J1.6, U6.1
GND: J1.9, J1.15, U7.12 (GND)

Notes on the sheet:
IN-12 Nixie Displays
Nixie Display Driver
Logic Board Connector

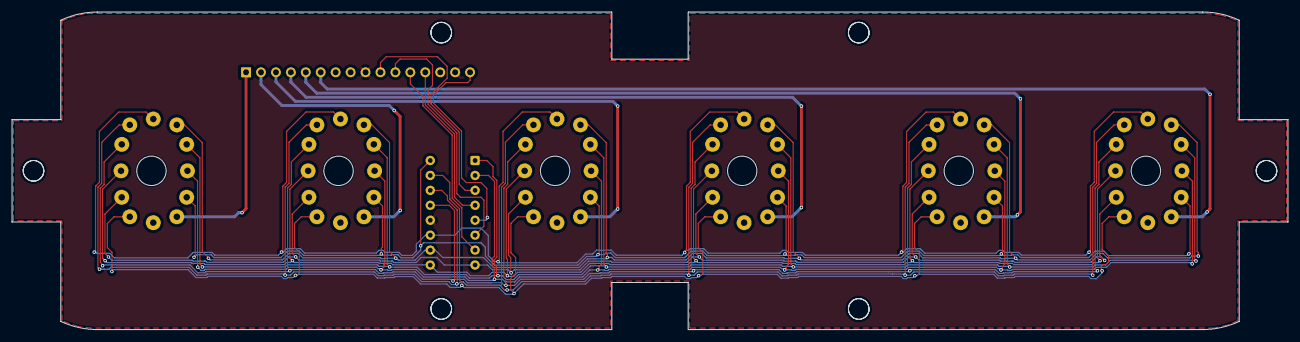
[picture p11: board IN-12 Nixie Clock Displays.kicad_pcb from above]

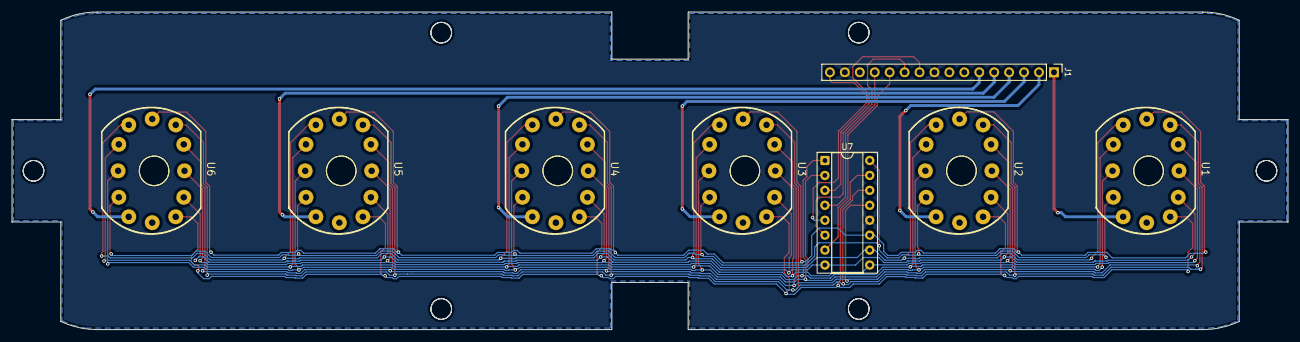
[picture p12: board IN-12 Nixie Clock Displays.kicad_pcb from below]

Board: 2 copper layers, 217.0 x 54.0 mm, 8 parts (8 on the bottom side), 22 nets.

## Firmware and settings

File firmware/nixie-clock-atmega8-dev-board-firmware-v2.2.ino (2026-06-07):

// -------------------------------------------------------------------------------------------- //
//                                     ATmega8 clock firmware                                   //
//                                   Test software version 2.2                                  //
//                              Used in strip board protoype for ISP                            //
// -------------------------------------------------------------------------------------------- //

#ifndef F_CPU
#define F_CPU 16000000UL
#endif

#include <EEPROM.h>
#include <avr/io.h>
#include <string.h>

// ************************************* Pin Assignments ************************************** //

//  AVR  PIN  Description
//  PD0 = 2 = Hours Tens Cathode
//  PD1 = 3  = Hours Units Cathode
//  PD2 = 4  = Mins Tens Cathode
//  PD3 = 5  = Mins Units Cathode
//  PD4 = 6  = Sec Tens Cathode
//  PD5 = 11 = Sec Units Cathode
//  PD6 = 12 = NC
//  PD7 = 13 = NC

//  PB0 = 14 = BCD A
//  PB1 = 15 = BCD B
//  PB2 = 16 = BCD C
//  PB3 = 17 = BCD D
//  PB4 = 18 = NC
//  PB5 = 19 = NC
//  PB6 = 9  = Crystal In
//  PB7 = 10 = Crystal In

//  PC0 = 23 = Nixie Run Time Button
//  PC1 = 24 = Hour Increment Button
//  PC2 = 25 = Minute Increment Button
//  PC3 = 26 = 180v On/Off
//  PC4 = 27 = Hour Mode Button
//  PC5 = 28 = Power Monitor Input
//  PC6 = 1  = Reset Input

// ************************************** Pin Assignments ************************************* //

const uint8_t BCD_PINS[4] =          {0, 1, 2, 3};                  // PORTB Outputs
const uint8_t DIGIT_PINS[6] =  {0, 1, 2, 3, 4, 5};                  // PORTD Outputs
const uint8_t COLON_PIN =                       6;                  // PD6
const uint8_t STATUS_PIN =                      0;                  // PC0 For showing EEPROM time data
const uint8_t HOUR_PIN =                        2;                  // PC1 Hour increment
const uint8_t MINUTE_PIN =                      1;                  // PC2 Minute increment
const uint8_t HV_POWER =                        3;                  // PC3 Turns on/off high voltage
const uint8_t MODE_PIN =                        4;                  // PC4 12/24 hour mode
const uint8_t PWR_PIN =                         5;                  // PC5 monitor standby switch

// *************************************** Enumerations *************************************** //

enum DisplayMode : uint8_t {
    TIME_MODE,
    HOUR_MODE,
    RUN_TIME_MODE,
    POISON_MODE,
    STANDBY_MODE
};
// ************************************** EEPROM Adresses ************************************* //

const uint8_t RUN_TIME_HOURS =                  4;                  // EEPROM address for nixie tube run time, 4 bytes 0 - 3
const uint8_t EEPROM_INITIALISED =             20;                  // EEPROM address to check if EEPROM is initialised

// ****************************************** Timing ****************************************** //

const uint8_t DEBOUNCE_DELAY =                100;                  // Time after button press to ignore inputs
const uint16_t POISON_DWELL =                  50;
const uint8_t POISON_REPEAT =                   4;

// *************************************** Character Data ************************************* //

const uint8_t BLANK =                          10;                  // Used for clear reference to CD4511 invalid data
const uint8_t BCD_CODES[11] = {0x00, 0x01, 0x02, 0x03, 0x04, 0x05, 0x06, 0x07, 0x08, 0x09, 0x0F};

// **************************************** Display Modes ************************************ //

volatile DisplayMode requestedMode =    TIME_MODE;
DisplayMode currentMode =               TIME_MODE;

// ****************************************** Bit Masks *************************************** //

const uint8_t CATHODES_OFF =           0b11000000;

// **************************************** Button States ************************************* //

uint8_t minuteButtonState =                 false;
uint8_t prevMinuteButtonState =             false;
uint8_t hourButtonState =                   false;
uint8_t prevHourButtonState =               false;
uint8_t modeButtonState =                   false;
uint8_t prevModeButtonState =               false;
uint8_t statusButtonState =                 false;
uint8_t prevStatusButtonState =             false;
uint8_t standbyButtonState =                false;
uint8_t prevStandbyButtonState =            false;

// **************************************** Button Debounce *********************************** //

uint32_t minuteButtonPrevPush =                 0;                             // Time when minute button was pressed last
uint32_t hourButtonPrevPush =                   0;                             // Time when hour button was pressed last
uint32_t modeButtonPrevPush =                   0;
uint32_t statusButtonPrevPush =                 0;
uint32_t currentButtonReferenceTime =           0;

// **************************************** Internal Flags ************************************ //

volatile uint8_t runTimer =                 false;
uint8_t colonState =                        false;
uint8_t multiplexFlag =                     false;
uint8_t twelveHourModeFlag =                false;
uint8_t modeSelectBlock =                   false;
uint8_t eepromWriteReady =                  false;
uint8_t poisonRunFlag =                     false;

// *************************************** EEPROM Variables *********************************** //

uint32_t eepromData =                           0;

// ******************************************* Counters *************************************** //

volatile uint8_t currentDigit =                 0;
volatile uint32_t milliSecondCounter =          0;
uint8_t systemTimer =                           0;
uint8_t counterSeconds =                        0;
uint8_t counterMinutes =                        0;
uint8_t counterHours =                          0;
uint8_t counterHoursCopy =                      0;
uint8_t poisonCycleDigit =                      0;
uint32_t poisonCycleLast =                      0;
uint8_t poisonCycleCount =                      0;

// **************************************** Display Buffers *********************************** //

uint8_t multiplexBuffer[6] =   {0, 0, 0, 0, 0, 0};
uint8_t timerBuffer[6] =       {0, 0, 0, 0, 0, 0};
uint8_t runTimeBuffer[6] =     {0, 0, 0, 0, 0, 0};
uint8_t hourModeBuffer[6] =    {0, 0, 0, 0, 0, 0};
uint8_t poisonBuffer[6] =      {0, 0, 0, 0, 0, 0};

// =========================================== Functions ====================================== //

void setup(void);
void loop(void);
void buttonHandler(uint8_t avrPin, uint8_t &buttonState, uint8_t &prevButtonState, uint32_t currentReferenceTime, uint32_t &buttonPrevPush);
void modeSelect(uint8_t logic);
void minuteButtonHandler(void);
void hourButtonHandler(void);
void displayBuffer(uint8_t displayMode);
void multiplex(void);
void eepromUpdate(void);
void twelveHourModeConversion(void);
void escapeToTimeMode(void);
void hourModeText(void);
void totalRunTimeText(void);
void cathodePoison(void);
void timer(void);
void timerBufferUpdate(void);
void standy(void);

// ============================================= Setup ======================================== //

void setup() {

  set_sleep_mode(SLEEP_MODE_IDLE);
  sleep_enable();
  
  // BCD Pins
  DDRB = 0b00001111;
  PORTB = 0b00110000;

  // Cathode Pins
  DDRD = 0b00111111;
  PORTD = 0b11000000;

  // Buttons/Feedback Pins
  DDRC = 0b00001000;                                              // Output on PC3
  PORTC = 0b00010111;                                             // No pullup on PC5

  cli();
  // Timer1 CTC - 16MHz
  TCCR1A = 0;
  TCCR1B = (1 << WGM12)|(1 << CS12);
  OCR1A = 62499;
  TIMSK |= (1 << OCIE1A);
/*
  // Timer1 CTC - 1MHz
  TCCR1A = 0;
  TCCR1B = (1 << WGM12)|(1 << CS12);
  OCR1A = 3906;                                             // wrong
  TIMSK |= (1 << OCIE1A);
*/  
  // Timer2 CTC - 16MHz
  TCCR2 |= (1 << WGM21)|(1 << CS22);
  TCNT2 = 0;
  OCR2 = 249;
  TIMSK |= (1 << OCIE2);

/*  // Timer2 CTC - 1MHz
  cli();
  TCCR2 |= (1 << WGM21)|(1 << CS21);                              // CTC Mode - prescaler 8
  TCNT2 = 0;
  OCR2 = 62;                                                      // 500ms for colon flash
  TIMSK |= (1 << OCIE2);
  sei();
*/
  byte nixieStorageInit = EEPROM.read(EEPROM_INITIALISED);        // Read initialised data from EEPROM

  if (nixieStorageInit != 0xAA) {                                 // Check if EEPROM was previously initialised.
    EEPROM.update(EEPROM_INITIALISED, 0xAA);                      // Address 4 is out the way of the previous data
    EEPROM.put(RUN_TIME_HOURS, 0UL);
  }
  sei();
}
// ============================================ 1Hz Timer ===================================== //

ISR(TIMER1_COMPA_vect) {
  timer();
}
// ========================================== Multiplex Timer ================================== //

ISR(TIMER2_COMP_vect) {
  milliSecondCounter++;
  multiplex();
}
// =============================================== Loop ======================================== //

void loop() {

  currentButtonReferenceTime = milliSecondCounter;              // Log time for comparing with last time button pressed

  standbyButtonState = !(PINC & (1 << PWR_PIN));                 // active low

  if (standbyButtonState != prevStandbyButtonState) {
    if (standbyButtonState) {
      standby();
    } else {
      wakeUp();
    }
    prevStandbyButtonState = standbyButtonState;
  }

  if (currentMode == HOUR_MODE) {
    hourModeText();
  }

  if (currentMode == RUN_TIME_MODE) {
    totalRunTimeText();
  }
  
  if (eepromWriteReady && currentMode != STANDBY_MODE) {
    eepromUpdate();
    eepromWriteReady = false;
    poisonRunFlag = true;
    modeSelect(POISON_MODE);
  }

  if (poisonRunFlag == true) {
    cathodePoison();
  }

  displayBuffer(currentMode);
  
  buttonHandler(HOUR_PIN,   hourButtonState,    prevHourButtonState,    currentButtonReferenceTime, hourButtonPrevPush);
  buttonHandler(MINUTE_PIN, minuteButtonState,  prevMinuteButtonState,  currentButtonReferenceTime, minuteButtonPrevPush);  
  buttonHandler(MODE_PIN,   modeButtonState,    prevModeButtonState,    currentButtonReferenceTime, modeButtonPrevPush);
  buttonHandler(STATUS_PIN, statusButtonState,  prevStatusButtonState,  currentButtonReferenceTime, statusButtonPrevPush);

  sleep_cpu();
}
// ======================================== Button Handler ==================================== //

void buttonHandler(uint8_t avrPin, uint8_t &buttonState, uint8_t &prevButtonState,
                   uint32_t currentReferenceTime, uint32_t &buttonPrevPush) {

  buttonState = !(PINC & (1 << avrPin));

  if (buttonState != prevButtonState) {

    if (currentReferenceTime - buttonPrevPush > DEBOUNCE_DELAY) {

      if (buttonState == true) {   // only trigger on press, not release
        switch(avrPin) {
          case MINUTE_PIN:
            minuteButtonHandler();
            break;

          case HOUR_PIN:
            hourButtonHandler();
            break;

          case MODE_PIN:
            requestedMode = HOUR_MODE;
            modeSelect(requestedMode);
            break;

          case STATUS_PIN:
            requestedMode = RUN_TIME_MODE;
            modeSelect(requestedMode);
            break;
        }
      }
      buttonPrevPush = currentReferenceTime;
    }
  }
  prevButtonState = buttonState;
}
// ========================================== Mode Select ===================================== //
/* Put stuff here that you want to run once when the new mode is activated. Repeated code goes
 *  in its own function.
 */

void modeSelect(DisplayMode requestedMode) {

  switch (requestedMode) {

    case TIME_MODE:
      currentMode = requestedMode;
      break;
      
    case HOUR_MODE:
      if (modeSelectBlock) {
        break;
      }
      currentMode = requestedMode;
      twelveHourModeFlag = !twelveHourModeFlag;
      modeSelectBlock = true;
      systemTimer = 0;
      break;
      
    case RUN_TIME_MODE:
      if (modeSelectBlock) {
        break;
      }
      currentMode = requestedMode;
      modeSelectBlock = true;
      systemTimer = 0;
      EEPROM.get(RUN_TIME_HOURS, eepromData);
      break;
      
    case POISON_MODE:
      if (modeSelectBlock) {
        break;
      }
      currentMode = requestedMode;
      cathodePoison();
      break;

    case STANDBY_MODE:
      if (modeSelectBlock) {
        break;
      }
      modeSelectBlock = true;
      currentMode = requestedMode;
      break;
  }
}
// ========================================= Display Buffer =================================== //

void displayBuffer(DisplayMode currentMode) {
  
  switch (currentMode) {

    case TIME_MODE:
      cli();
      memcpy(multiplexBuffer, timerBuffer, 6);    // Copy 6 bytes from timer to multi
      sei();
      break;
      
    case HOUR_MODE:
      cli();
      memcpy(multiplexBuffer, hourModeBuffer, 6); // Look at using pointers instead of copying mem
      sei();
      break;
      
    case RUN_TIME_MODE:
      cli();
      memcpy(multiplexBuffer, runTimeBuffer, 6);
      sei();
      break;
      
    case POISON_MODE:
      cli();
      memcpy(multiplexBuffer, poisonBuffer, 6);
      sei();
      break;

    case STANDBY_MODE:
      break;
  }
}
// ========================================= EEPROM Update ==================================== //

void eepromUpdate() {

  uint32_t runTimeEeprom = 0;
  
  EEPROM.get(RUN_TIME_HOURS, runTimeEeprom);
  runTimeEeprom++;
  EEPROM.put(RUN_TIME_HOURS, runTimeEeprom);
}
// ===================================== Minute button handler ================================ //

void minuteButtonHandler() {
 
    counterMinutes = (counterMinutes + 1) % 60;
    timerBufferUpdate();
}
// ====================================== Hour button handler ================================= //

void hourButtonHandler() {

    counterHours = (counterHours + 1) % 24;
    counterHoursCopy = counterHours;
    
    if (twelveHourModeFlag) {
      twelveHourModeConversion();
    }
    timerBufferUpdate();
}
// ====================================== Escape To Time Mode ================================= //

void escapeToTimeMode() {

    modeSelectBlock = false;
    requestedMode = TIME_MODE;
    modeSelect(requestedMode);
}
// ========================================= Run Time Mode ==================================== //

void totalRunTimeText() {

  if (systemTimer < 5) {                                // eg 123456 hours run
    runTimeBuffer[0] = (eepromData / 100000) % 10;      // 1
    runTimeBuffer[1] = (eepromData / 10000) % 10;       // 2
    runTimeBuffer[2] = (eepromData / 1000) % 10;        // 3
    runTimeBuffer[3] = (eepromData / 100) % 10;         // 4
    runTimeBuffer[4] = (eepromData / 10) % 10;          // 5
    runTimeBuffer[5] = eepromData % 10;                 // 6
  } else {
  escapeToTimeMode();
  }
}
// ========================================= Hour Mode Text =================================== //

void hourModeText() {

  if (systemTimer < 2) {
    if (twelveHourModeFlag){
      hourModeBuffer[0] = BLANK;
      hourModeBuffer[1] = BLANK;
      hourModeBuffer[2] = 1;
      hourModeBuffer[3] = 2;
      hourModeBuffer[4] = BLANK;
      hourModeBuffer[5] = BLANK;
    } else {
      hourModeBuffer[0] = BLANK;
      hourModeBuffer[1] = BLANK;
      hourModeBuffer[2] = 2;
      hourModeBuffer[3] = 4;
      hourModeBuffer[4] = BLANK;
      hourModeBuffer[5] = BLANK;
    }
  } else {
  escapeToTimeMode();
  }
}
// ======================================= Cathode Poisoning ================================== //

void cathodePoison() {

  if ((milliSecondCounter - poisonCycleLast) >= POISON_DWELL) {
    for (byte i = 0; i < 6; i++) {
      poisonBuffer[i] = poisonCycleDigit;
    }
    poisonCycleDigit++;
      
    if (poisonCycleDigit > 9) {
      poisonCycleDigit = 0;
      poisonCycleCount++;
    }

    if (poisonCycleCount >= POISON_REPEAT) {
      poisonCycleCount = 0;
      poisonCycleDigit = 0;
      poisonRunFlag = false;                 // Mode request stops this displaying, not setting
      escapeToTimeMode();                    // flag to false keeps this running in background!
    }
    poisonCycleLast = milliSecondCounter;
  }
}
// =========================================== Multiplex ====================================== //

void multiplex()
{
  uint8_t num = 0;
  uint8_t bcd = 0;

  num = multiplexBuffer[currentDigit];         // Find number to display in digit array   
  bcd = BCD_CODES[num];                        // Find character data for current number

  PORTD &= CATHODES_OFF;                       // Turn off all cathodes
  PORTB = BCD_CODES[BLANK];
  _delay_us(10);
  PORTB = bcd;                                 // Set outputs to character data, !!bit mask due to XTAL inputs
  PORTD |= (1 << (5 - currentDigit));
  currentDigit++;
  
  if (currentDigit >= 6) {                     // If next digit is 6 or more, wrap to 0
    currentDigit = 0;
  }
}
// ======================================= 12 Hour Conversion ================================= //

void twelveHourModeConversion() {

  if (counterHours > 12) {                     // Convert 24 hour mode into 12 hour mode data
    counterHoursCopy -= 12;
  } else if (counterHours == 0) {
    counterHoursCopy = 12;
  }
}
// ============================================= Timer ======================================== //

void timer() {

  counterSeconds++;

  if (counterSeconds >= 60) {
    counterSeconds = 0;
    counterMinutes++;
  }

  if (counterMinutes >= 60) {
    counterMinutes = 0;
    counterHours++;
    eepromWriteReady = true;
  }

  if (counterHours >= 24) {
    counterHours = 0;
  }

  counterHoursCopy = counterHours;

  if (twelveHourModeFlag) {
    twelveHourModeConversion();
  }

  timerBufferUpdate();

  if (currentMode != TIME_MODE) {
    systemTimer++;
  }
}
// ========================================= Timer Buffer Update =============================== //

void timerBufferUpdate() {

  timerBuffer[0] = (counterHoursCopy / 10) % 10;             // Find tens
  timerBuffer[1] = (counterHoursCopy % 10);                  // Find units
  timerBuffer[2] = (counterMinutes / 10) % 10;
  timerBuffer[3] = (counterMinutes % 10);
  timerBuffer[4] = (counterSeconds / 10) % 10;
  timerBuffer[5] = (counterSeconds % 10);
}
// ============================================ Standby ========================================= //

void standby() {

  TIMSK &= ~(1 << OCIE2);
  PORTD = CATHODES_OFF;
  PORTC &= ~(1 << HV_POWER);
  requestedMode = STANDBY_MODE;
  modeSelect(requestedMode);
}
// ============================================ Wake Up ========================================= //

void wakeUp() {

  PORTC |= (1 << HV_POWER);
  TIMSK |= (1 << OCIE2);
  escapeToTimeMode();
}

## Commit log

2025-11-02 Add files via upload
    version 1.4 - battery backup function
2025-11-07 Delete nixie-clock-atmega8-dev-board-firmware-29-10-2025.7z
    organising files
2025-11-07 Delete nixie-clock-atmega8-dev-board-firmware-26-10-2025.7z
    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
2025-11-07 Delete nixie-clock-atmega8-dev-board-firmware-27-10-2025.7z
    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
2025-11-07 Delete nixie-clock-atmega8-dev-board-firmware-30-10-2025-v1.2.7z
    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
2025-11-07 Delete nixie-clock-atmega8-dev-board-firmware-31-10-2025-v1.3.7z
    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
2025-11-07 Delete nixie-clock-atmega8-dev-board-firmware-v1.31.7z
    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
2025-11-07 Delete nixie-clock-atmega8-dev-board-firmware-v1.4.7z
    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
2025-11-07 Delete nixie-clock-atmega8-dev-board-firmware-v1.45.7z
    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
2025-11-07 Delete nixie-clock-atmega8-dev-board-firmware.ino
    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
2025-11-19 Update README.md
    Explanation of of PCB and housing "keying" and more 3D mock ups added
2025-11-25 Add files via upload
    Added all but missing v1.7
    [nixie-clock-atmega8-dev-board-firmware-v1.71.ino, nixie-clock-atmega8-dev-board-firmware-v1.8.ino]
2026-06-04 Add files via upload
    Current state photos and renders added
2026-06-05 Update README.md
    full bom
2026-06-05 Update README.md
    transistor added to bom
2026-06-09 Update README.md
    Updated progress:
    case done
    pcb rev done
    usb c done
    code features done
    started atmega328 port
    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
2026-06-09 Create POWER_USAGE_TESTS.md
    began recording power usage data
2026-06-10 Update POWER_USAGE_TESTS.md
    2mhz results added 2 max power saving options
2026-06-12 Update README.md
    Updated intro to match current progress.
    Updated parts list to be more brief.
    Updated software log to V2.2.3
2026-06-12 Add files via upload
    parts for you
    [BOM.csv]
2026-06-12 Update README.md
    added section on battery charging
2026-06-24 Update POWER_USAGE_TESTS.md
    typo
